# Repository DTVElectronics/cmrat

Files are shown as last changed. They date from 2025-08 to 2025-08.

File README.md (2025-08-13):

# CmRat by DTV Electronics

---

Please note: This repository is still under construction. Some files may be missing and will be uploaded soon.

---

The ‘CmRat’ carrier board allows a variety of Compute Modules (CM) to be installed and used alongside an NVMe hard drive. All the required expansion slots such as MicroSD, USB-C and a GPIO port to support a variety of Software/Linux and other FOSS solutions are also included.

Once configured the CmRat is capable of functioning as a fully-fledged micro server when paired with appropriate software. It operates consistently and robustly, ensuring reliable performance over time. Notably, it runs quietly, consumes minimal power, and boasts a compact physical form factor. These features make it an ideal choice for environments where space, energy efficiency, and reliable operation are paramount, such as home automation systems, small businesses, or edge computing setups.

Specifications:
- NVMe is designed for running the fastest/most reliable hard drives
- Ethernet and LCD Screen Support (via GPIO)
- POE, USB-C, or DC12v powered
- Large Heatsink design and quiet fan included
- Variety of 3d Printed Case designs on the market
- Designed for running Raspberry RPi CM4, CM5 or Radxa CM3/CM5

The project was originally developed by [Mirek](https://github.com/mfolejewski) under the project name ‘BitPiRat’ and has spurred a few different generations since then, with DTV Electronics finally releasing the project under the final retail version 2.8. 

Please take a look at the [included spec sheet](./spec-sheet.pdf) for more information.

## Table of Contents

- [CmRat by DTV Electronics](#cmrat-by-dtv-electronics)
  - [Table of Contents](#table-of-contents)
  - [About this repository](#about-this-repository)
  - [PCB Layout](#pcb-layout)
    - [Original Concept](#original-concept)
    - [BitPiRat Second Generation](#bitpirat-second-generation)
    - [CmRat project continues via DTV Electronics](#cmrat-project-continues-via-dtv-electronics)
    - [Final 2.8 Release Version from DTV Electronics](#final-28-release-version-from-dtv-electronics)
  - [Cases](#cases)
    - [Aluminium Retail Case](#aluminium-retail-case)
    - [3D Printed Third Party Cases](#3d-printed-third-party-cases)
  - [Add-ons](#add-ons)
    - [Examples](#examples)
  - [Supporters/Contributors](#supporterscontributors)

## About this repository

This repository contains the full manufacturing files for the CmRat, alongside spec sheets, pictures, and 3D models.

The repository is structured as follows:

- `readme-pictures/`: Contains images used in this README.
- `photos/`: Contains additional photos of the CmRat hardware.
- `manufacturing-files/`: Contains the manufacturing files for the CmRat.
  - `manufacturing-files/main-board/`: Contains Altium files for the main board of the CmRat.
  - `manufacturing-files/add-ons/`: Contains files for various add-ons.
    - `manufacturing-files/add-ons/lcd-module/`: Contains files for the LCD module add-on.
    - `manufacturing-files/add-ons/push-button/`: Contains files for the push button add-on.
- `3d-models/`: Contains 3D models of the CmRat.
- `spec-sheet.pdf`: A PDF document containing the specifications of the CmRat.
- `LICENSES/`: Contains the licenses for the manufacturing files and other content in this repository.
- `README.md`: This README file, providing an overview of the CmRat and its components.

All files in the manufacturing-files and 3d-models directory are licensed under the [CERN Open Hardware Licence Version 2 - Strongly Reciprocal](./LICENSES/CERN-OHL-S-2.0.txt).

All other files in this repository are licensed under the [Creative Commons Attribution-ShareAlike 4.0 International License](./LICENSES/CC-BY-SA-4.0.txt).

## PCB Layout

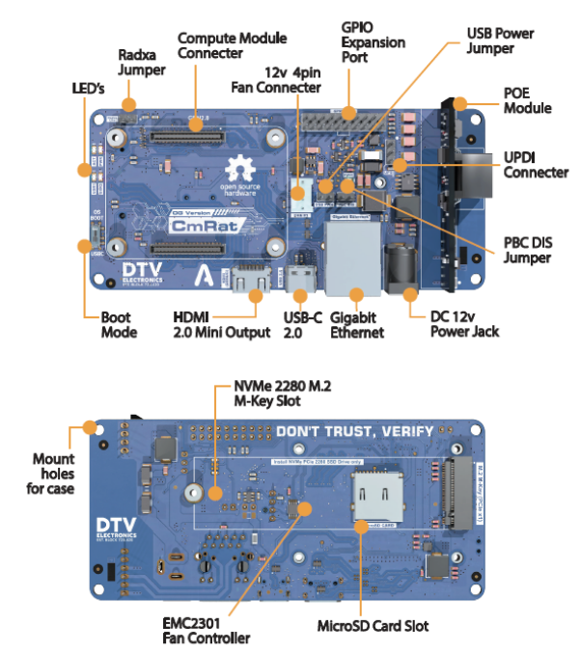
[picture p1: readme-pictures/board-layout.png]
Board Layout


### Original Concept

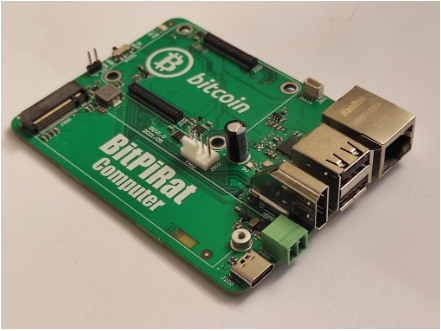
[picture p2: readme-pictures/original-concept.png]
Original Concept


### BitPiRat Second Generation

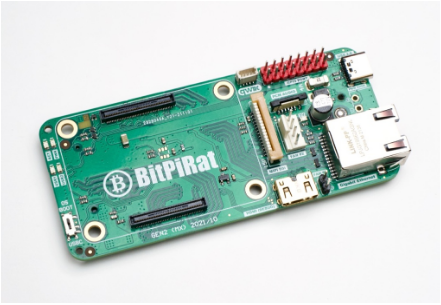
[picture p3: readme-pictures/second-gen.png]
BitPiRat Second Generation


### CmRat project continues via DTV Electronics

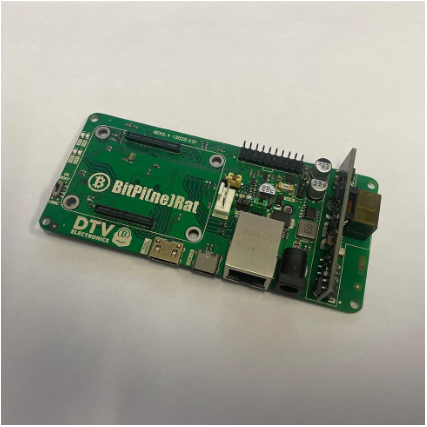
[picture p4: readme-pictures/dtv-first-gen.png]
CmRat Project Continues


### Final 2.8 Release Version from DTV Electronics

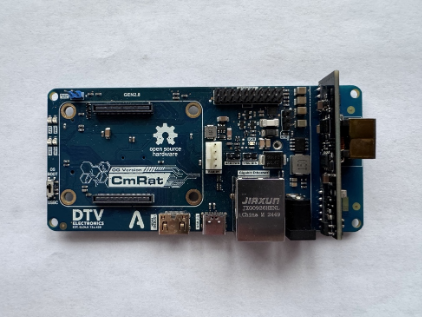
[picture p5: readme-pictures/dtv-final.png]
Final 2.8 Release Version


## Cases

### Aluminium Retail Case

The case has been designed from scratch by DTV Electronics using injection moulded production from secure and high quality ADC12 Aluminium materials. 

A fully CNC made and die casted mould allows enough airflow to keep the device running cool and quiet.

All connecter inputs are lined up perfectly within the unit allowing easy access when adding or removing cables. The PCB attaches to the bottom of the case with only 4 screws which secures everything in its entirety. The aluminium case is professionally oil painted and comes in a variety of colours. As it is essentially 2 parts (top and bottom), it allows a large amount of customisation and a variety of colours.

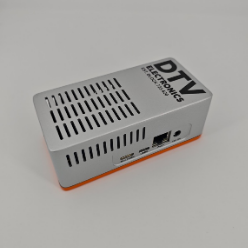
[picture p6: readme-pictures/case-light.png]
CmRat Case Light
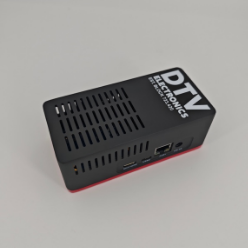
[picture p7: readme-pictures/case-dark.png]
CmRat Case Dark
 

### 3D Printed Third Party Cases

There are a variety of 3d printed inspired cases online and the files are included in this repository. 

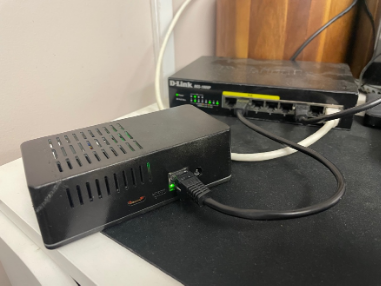
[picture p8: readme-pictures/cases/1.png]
Case 1

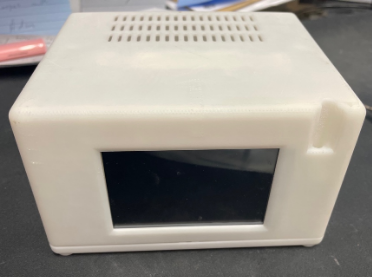
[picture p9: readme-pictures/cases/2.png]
Case 2

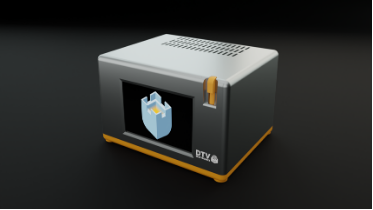
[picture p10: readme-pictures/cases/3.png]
Case 3

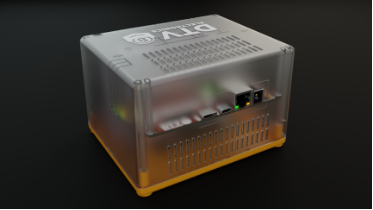
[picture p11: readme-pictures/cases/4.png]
Case 4

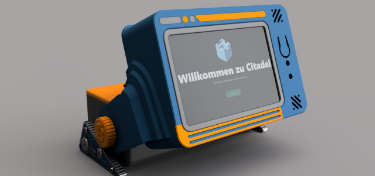
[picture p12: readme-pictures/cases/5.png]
Case 5


## Add-ons

A variety of add-ons that were originally developed by Mirek and DTV Electronics together which are included in the manufacturing files. These were not released in the retail version due to cost. The product was brought to market using only the slim case. However, there is an LCD module, Push Button Firmware, and a Push Button Controller.

This allows a screen to be attached via the GPIO port along with an on and off switch. This would have formed the concept for a larger case (shown above and listed as a 3d printed asset under ‘Max’)

All files necessary for the add-ons are included in the `manufacturing-files/addons/` directory. The firmware for the screen and push button controller is also included in the `manufacturing-files/addons/firmware/` directory. 

### Examples

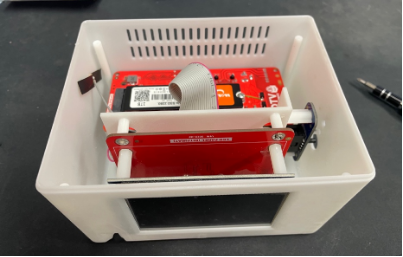
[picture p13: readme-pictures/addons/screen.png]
Screen Add-On 1

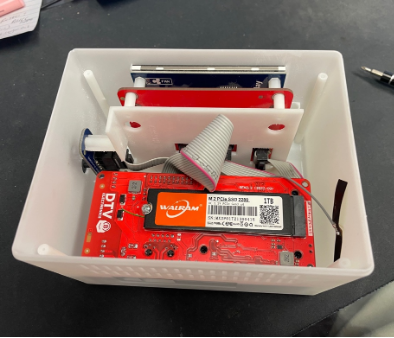
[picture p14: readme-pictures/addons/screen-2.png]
Screen Add-On 2


## Supporters/Contributors

- Adam of ‘Anlumen Technologies’
- Mirek of ‘PineBoards’
- Leo of ‘BuryRoadLabs’
- Aaron Dewes - Master Developer
- PrintergoBrr

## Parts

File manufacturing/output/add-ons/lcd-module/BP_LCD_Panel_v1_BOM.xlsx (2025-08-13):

Designator | Quantity | Component Type | Value | Package (Case) | Manufacturer | MPN | Description
C1, C2 | 2 | Capacitor | 10uF | 0603 (1608) | GENERIC | GENERIC | Capacitor; MLCC; GENERIC; TBD; TBD; TBD; TBD; SMD; 0603 (1608);
J1 | 1 | Connector | 26pin (2x13pin) | THT | GENERIC | GENERIC | Connector; 2 Row;
J2 | 1 | Connector | 20pin (2x10pin) | THT | GENERIC | GENERIC | Connector; 2 Row;
J3 | 1 | Connector | 8pin (2x4pin) | THT | GENERIC | GENERIC | Connector; 2 Row;
R1, R2, R3, R4, R5, R6, R7, R8 | 8 | Resistor | 22R | 0603 (1608) | Yageo Corporation | TBD | Resistor; Thick Film; 22R; 1%; 100mW; 100PPM; 75V; Standard; SMD; 0603 (1608);

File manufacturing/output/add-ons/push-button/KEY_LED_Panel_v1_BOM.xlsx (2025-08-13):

Designator | Quantity | Component Type | Value | Package (Case) | Manufacturer | MPN | Description
J1 | 1 | Connector | 8pin (2x4pin) | THT | GENERIC | GENERIC | Connector; 2 Row;
LED1 | 1 | LED | Green | 0805 (2012) | Foshan NationStar Optoelectronics | NCD0805G1 | Diode; LED; Green;
LED2 | 1 | LED | Red | 0805 (2012) | Foshan NationStar Optoelectronics | NCD0805R1 | Diode; LED; Red;
LP1, LP2 | 2 | Light pipe | VLP-400-F |  | BIVAR |  | LED; Light pipe
R1 | 1 | Resistor | 15k | 0603 (1608) | Yageo Corporation | TBD | Resistor; Thick Film; 15k; 1%; 100mW; 100PPM; 75V; Standard; SMD; 0603 (1608);
R2 | 1 | Resistor | 2k | 0603 (1608) | Yageo Corporation | TBD | Resistor; Thick Film; 2k2; 1%; 100mW; 100PPM; 75V; Standard; SMD; 0603 (1608);
SW1 | 1 |  | TACT Switch |  | SCHURTER | 1301.9319 | Switch; Tactile; Monostable;

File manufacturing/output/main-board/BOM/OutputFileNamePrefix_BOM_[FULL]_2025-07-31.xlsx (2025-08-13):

Designator | Quantity | Description | Value | Package (Case) | Manufacturer | MPN
C100 | 1 | Capacitor; MLCC; 100uF 6V3 | 100uF/6V3 | 1206 | Taiyo Yuden | JMK316ABJ107ML-T
C200, C908, C909, C911 | 4 | Capacitor; MLCC; 22u 16V | 22uF/16V | 0805 | Samsung Electro-Mechanics | CL21A226MOQNNNE
C303, C307, C309, C613, C702, C703, C704, C900, C912, C915, C916, C917, C918, C919, C920 | 15 | CAP SMD 10u/10V ±10% 10V X5R (0603) | 10uF | 0603 | Samsung Electro-Mechanics | CL10A106KP8NNNC
C304, C308, C310, C500, C700, C701, C800, C901 | 8 | Capacitor; MLCC; 100nF; 10V X5R | 100nF | 0603 | YAGEO | CC0603KRX7R9BB104
C400, C401, C402, C403, C404, C405, C406, C407 | 8 | RES SMD 0Ω ±1% 62.5mW ±800ppm (0402) |  |  | UNI-ROYAL(Uniroyal Elec)
C902, C906 | 2 | CAP SMD 100u/6.3V ±20% 6.3V X5R (1206) | 100u/6.3V | 1206 | Samsung Electro-Mechanics | CL31A107MQHNNNE
C903, C904 | 2 | CAP SMD 10u/50V ±10% 50V X5R (1206) | 10u/50V | 1206 | Samsung Electro-Mechanics | CL31A106KBHNNNE
C905 | 1 | CAP SMD 1u/50V ±10% 50V X5R (0603) | 1u/50V | 0603 | Samsung Electro-Mechanics | CL10A105KB8NNNC
C910, C913, C921, C922 | 4 | CAP SMD 100u/16V ±20% 16V X5R (1210) | 100uF | 1210 | Chinocera | HGC1210R5107M160NSVK
C914 | 1 | Capacitor; MLCC; 22p 50V | 22pF | 0603 | Samsung Electro-Mechanics | CL10C220JB8NNNC
D900 | 1 | Diode; Schottky; Unipolar; SMAj5.0A | SMAJ5.0A | SMA | Littelfuse | SMAJ5.0A
D901, D902 | 2 | Diode; Schottky; Unipolar; SS13 | SS13 (1A/30V) | DO-214AC (SMA) | ON Semi | SS13
D903 | 1 | Diode; Schottky; Unipolar; SK33 | SK33 (3A/SMC) | SMC | Littelfuse | SK33
D904 | 1 | DIODE SMD / SCHOTTKY / 40V 1A 600mV @ 1A (SOD-323) |  | SOD-323 | Guangdong Hottech | 1N5819WS
FUS900 | 1 | Fuse 4A | 4A/125VDC | SMD,6.1x2.5mm | Bel Fuse | 0679L4000-01
J100 | 1 | CONN THT / HEADER / PITCH 2,54mm / VERTICAL / (20 PIN) 2x10 | HDR 2x10 | THT | Ckmtw(Shenzhen Cankemeng) | B-2100S20P-B110
J103, J104 | 2 | Connector; DF40HC(3.0)-100DS-0.4V | Mezzanine, 100pin, 3.0mm | SMD | Hirose | DF40HC(3.0)-100DS-0.4V
J200 | 1 | Connector; USB 3.1 Type C; Receptacle; 24-pin; USB 2.0 Only; | U262-161N-4BVC11 | SMD | XKB Connectivity | U262-161N-4BVC11
J201, J601, J900 | 3 | CONN THT / HEADER / PITCH 2,54mm / VERTICAL / (2 PIN) | HDR 1x2 | THT | Ckmtw(Shenzhen Cankemeng) | B-2100S02P-A110
J300 | 1 | Connector; NGFF (M.2); M-Key; | M.2/NGFF M-Key H4.2 | SMD | Lotes | APCI0107-P001A
J400 | 1 | Connector; HDMI v1.4+; Type C (Mini-HDMI); | Mini HDMI connector (Type C), angled, SMD | SMD | XKB Connectivity | A71-05H4-111N1
J500 | 1 | Connector; RJ45; | LPJG0926HENL | THT | Link-PP | LPJG0926HENL
J501 | 1 | Connector; DC Barrel Jack; | 5A, 2.0mm | THT | XKB Connectivity | DC-005-5A-2.0
J600 | 1 | Connector; MicroSD Card Connector; | MicroSD Card (Slot) | SMD | TF-015 | TF-015
J802 | 1 | Connector; 1 Row; 470531000 | MLX 470531000 | THT | Molex | 470531000
J901 | 1 | CONN THT / HEADER / PITCH 2,54mm / VERTICAL / (3 PIN) | HDR 1x3 | THT | Ckmtw(Shenzhen Cankemeng) | B-2100S03P-A110
L900 | 1 | Inductor; 15u | 15uH | SMD | Changjiang Microelectronics Tech | FXL0630-150-M
L901, L903 | 2 | Inductor; 2u2 | 2u2H | SMD | Changjiang Microelectronics Tech | FXL0624-2R2-M
L902 | 1 | INDUCTOR SMD COIL / 4u7 ±20% / Power inductor Ir 2.8A Isat 3A (SMD,4.2x4.4mm) | 4u7 | SMD,4.2x4.4mm | cjiang (Changjiang Microelectronics Tech) | FXL0420-4R7-M
LED100, LED801 | 2 | Diode; LED; Red; | Red | 0805 | Foshan NationStar Optoelectronics | NCD0805R1
LED101, LED800, LED900 | 3 | Diode; LED; Green; | Green | 0805 | Foshan NationStar Optoelectronics | NCD0805G1
MECH301 | 1 | PCB; Mechanical; SMT Steel Spacer; M2.5; | M2.5, L = 2.5mm | SMD | Wurth Elektronik | 977 402 515 1
MECH800, MECH801, MECH804, MECH805 | 4 | PCB; Mechanical; SMT Steel Spacer; M2.5; | M2.5, L = 3.0mm | SMD | Wurth Elektronik | 977 403 015 1
MECH802, MECH803, MECH806, MECH807, SCR300 | 5 | Mechnical; Screw; | M2.5 |  |  | M2.5 screw
MOD100 | 1 | PCB Module; RPi Compute Module 4; | RPi CM4 Module |  | Raspberry Pi Foundation | CM4 Module
MOD900 | 1 | PCB Module; PoE Module; | DP9712 |  | SDaPo | DP9712
Q200, Q803, Q902 | 3 | Transistor; BJT; NPN; Digital; | DTC143ZE | SOT-523 | On Semiconductor | DTC143ZE
Q800, Q801, Q802 | 3 | Transistor; BJT; PNP; Digital; | DTA143ZE | SOT-523 | On Semiconductor | DTA143ZE
Q900, Q901 | 2 | Transistor; PMOS; | PMOS | SOT23 | Vishay | SI2305CDS-T1-GE3
R100, R201, R203, R205, R903, R915 | 6 | Resistor; Thick Film; 5k1; 1%; 100mW; 100PPM; 75V; Standard; SMD; 0603 (1608); | 5k1 | 0603 | UNI-ROYAL(Uniroyal Elec) | 0603WAF5101T5E
R200, R207, R713, R714 | 4 | Resistor; Thick Film; 1k; 1%; 100mW; 100PPM; 75V; Standard; SMD; 0603 (1608); | 1k | 0603 | UNI-ROYAL(Uniroyal Elec) | 0603WAF1001T5E
R202, R703, R715, R800, R804, R900, R901, R913 | 8 | Resistor; Thick Film; 15k; 1%; 100mW; 100PPM; 75V; Standard; SMD; 0603 (1608); | 15k | 0603 | UNI-ROYAL(Uniroyal Elec) | 0603WAF1502T5E
R206, R904 | 2 | Resistor; Thick Film; 100k; 1%; 100mW; 100PPM; 75V; Standard; SMD; 0603 (1608); | 100k | 0603 | UNI-ROYAL(Uniroyal Elec) | 0603WAF1003T5E
R400, R700, R701, R702, R705, R708, R709, R710, R802, R805, R920 | 11 | Resistor; Thick Film; 2k2; 1%; 100mW; 100PPM; 75V; Standard; SMD; 0603 (1608); | 2k | 0603 | UNI-ROYAL(Uniroyal Elec) | 0603WAF2001T5E
R401, R600, R803 | 3 | Resistor; Thick Film; 0R; SMD; 0603 (1608); | 0R | 0603 | UNI-ROYAL(Uniroyal Elec) | 0603WAF0000T5E
R500, R501, R704 | 3 | Resistor; Thick Film; 470R; 1%; 100mW; 100PPM; 75V; Standard; SMD; 0603 (1608); | 470R | 0603 | UNI-ROYAL(Uniroyal Elec) | 0603WAF4700T5E
R706, R707 | 2 | Resistor; Thick Film; 20k; SMD; 0603 (1608); | 20k | 0603 | UNI-ROYAL(Uniroyal Elec) | 0603WAF2002T5E
R716 | 1 | Resistor; Thick Film; 100R; 1%; 100mW; 100PPM; 75V; Standard; SMD; 0603 (1608); | 100R | 0603 | UNI-ROYAL(Uniroyal Elec) | 0603WAF1000T5E
R801 | 1 | Resistor; Thick Film; 36k; SMD; 0603 (1608); | 36k | 0603 | UNI-ROYAL(Uniroyal Elec) | 0603WAF3602T5E
R902 | 1 | Resistor; Thick Film; 5k1; 1%; 100mW; 100PPM; 75V; Standard; SMD; 0603 (1608); | 300k | 0603 | UNI-ROYAL(Uniroyal Elec) | 0603WAF3003T5E
R905 | 1 | Resistor; Thick Film; 22k; 1%; 100mW; 100PPM; 75V; Standard; SMD; 0603 (1608); | 22k | 0603 | UNI-ROYAL(Uniroyal Elec) | 0603WAF2202T5E
R914 | 1 | Resistor; Thick Film; 6k2; SMD; 0603 (1608); | 6.2k | 0603 | UNI-ROYAL(Uniroyal Elec) | 0603WAF6201T5E
SW200 | 1 | Switch; SPDT; | Slide switch | SMD | XKB Connectivity | SS-3292S-L1
U100 | 1 | IC SMD / REGULATOR - CONVERTER (INT SWI) - DC/DC - STEP-UP / 1.4A 2.7-16VIN 1MHz (SOT-23-6) |  | SOT-23-6 | Diodes Incorporated | AP3031KTR-G1
U200, U400, U401, U500, U501 | 5 | IC; TVS Arrays; ESD Protection; 4-Channel; 17kV Air; 12kV Contact; 0.3pF Capitance; TBD; SMD; TBD; | RCLAMP0524PA | DFN-10(1x2.5) | Semtech Corporation | RCLAMP0524PATCT
U201 | 1 | IC SMD / LOAD SWITCH / 2.4V - 5.5V (SOT-23-5) | SY6280AAC | SOT-23-5 | Silergy Corp | SY6280AAC
U700 | 1 | IC; MCU; tinyAVR 8-bit MCU, 20MHz, 8kB flash, 512B RAM, USART, SPI, TWI, VQFN package | ATTINY806 | VQFN20 | Microchip Technology (Atmel) | ATTINY806-MNR
U701 | 1 | ICC; LDO regulator; AP2210N-3.3, Ultra-low dropout voltage regulator, Vout = 3.3V, 300 mA, SOT23-3 package | AP2210N-3.3 | SOT23-3 | Diodes Incorporated | AP2210N-3.3TRG1
U801 | 1 | IC; Fan controller; | EMC2301 | MSOP-8 | Microchip Technology | EMC2301-1-ACZL-TR
U900 | 1 | IC; Buck regulator; AP3441 | AP3441/L | U-DFN2020-8 | Diodes Incorporated | AP3441SHE-7B
U902 | 1 | IC; Buck regulator; TD1583 | TD1583 | SOP8 | Techcode Semicon | TD1583PR

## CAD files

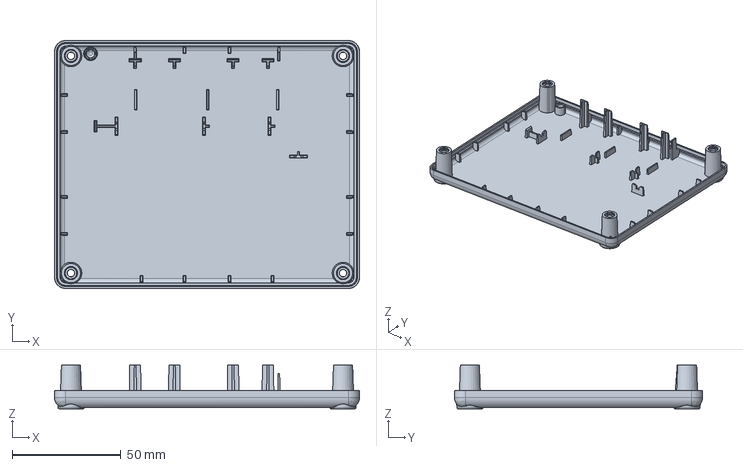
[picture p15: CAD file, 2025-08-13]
3d-models/max/02_max_bottom_cc_24.stp
140.1 x 113.9 x 20.0 mm

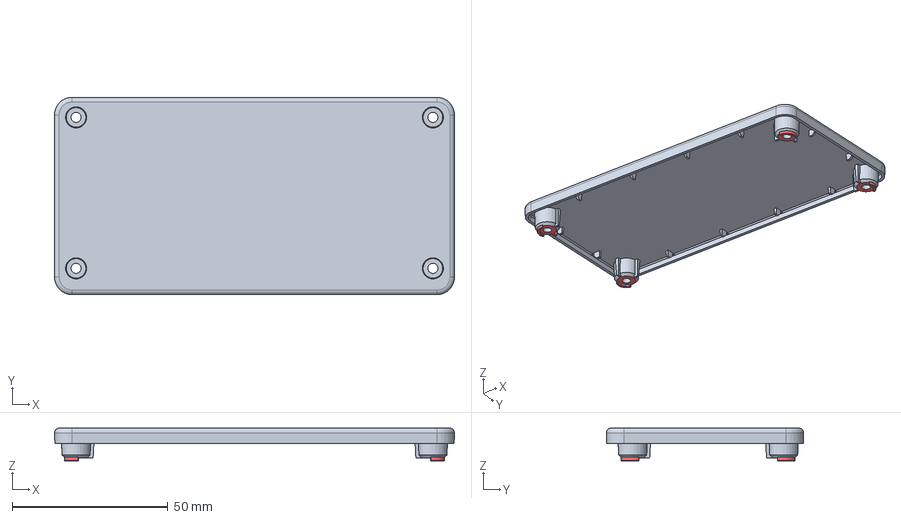
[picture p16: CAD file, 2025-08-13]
3d-models/slim/02_slim_bottom_r3_10_3_1-20231213.stp
128.2 x 63.2 x 10.5 mm

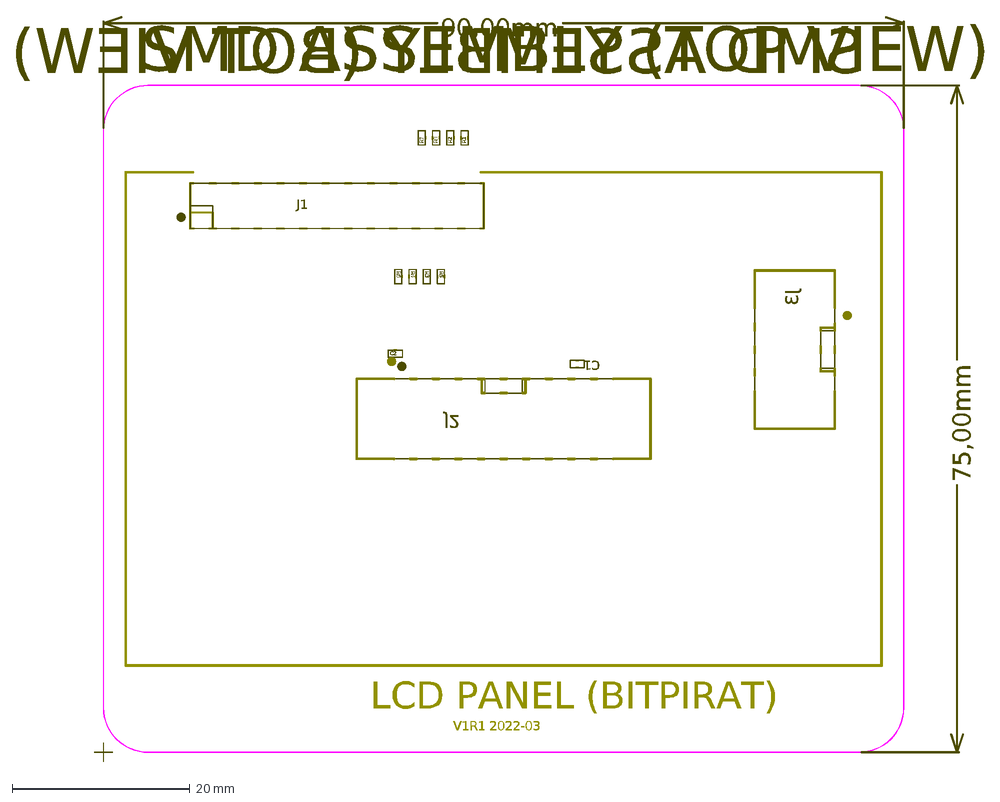
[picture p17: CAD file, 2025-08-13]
manufacturing/output/add-ons/lcd-module/BP_LCD_Panel_v1.DXF
SMD ASSEMBLY (BOT VIEW)
SMD ASSEMBLY (TOP VIEW)
LCD PANEL (BITPIRAT)
V1R1 2022-03
90,00mm
75,00mm
J3
C2
R8
R7
R6
R5
R4
R3
R2
R1
J2
J1
C1

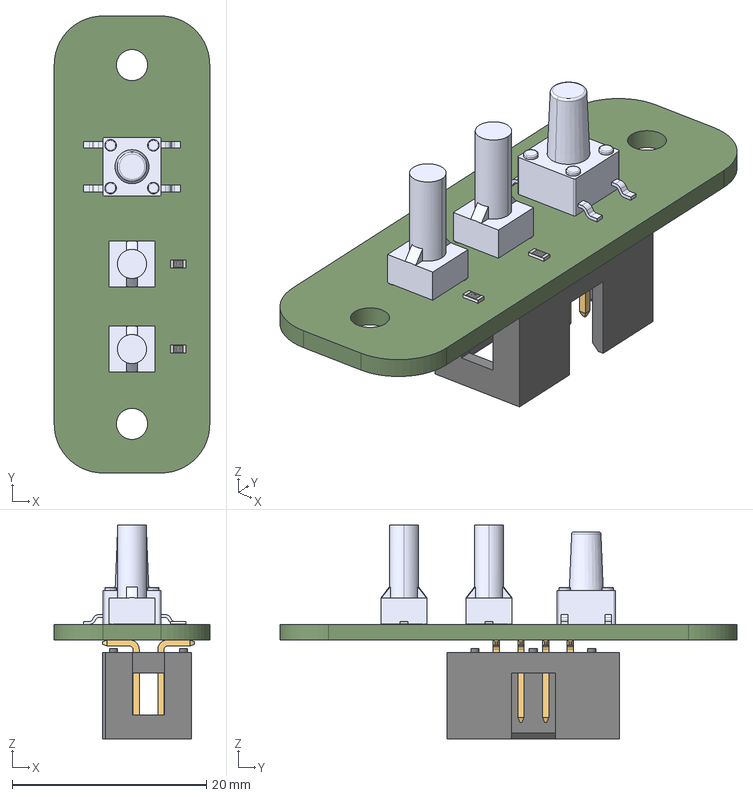
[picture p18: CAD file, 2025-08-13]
manufacturing/output/add-ons/push-button/KEY_LED_Panel_v1.step
16.0 x 47.0 x 22.0 mm
BIVAR_VLP-400-F x 2
User_Library-led_0805
User_Library-led_0805G
6120xx20621_PIN x 8
RESC1608X_0603 x 2

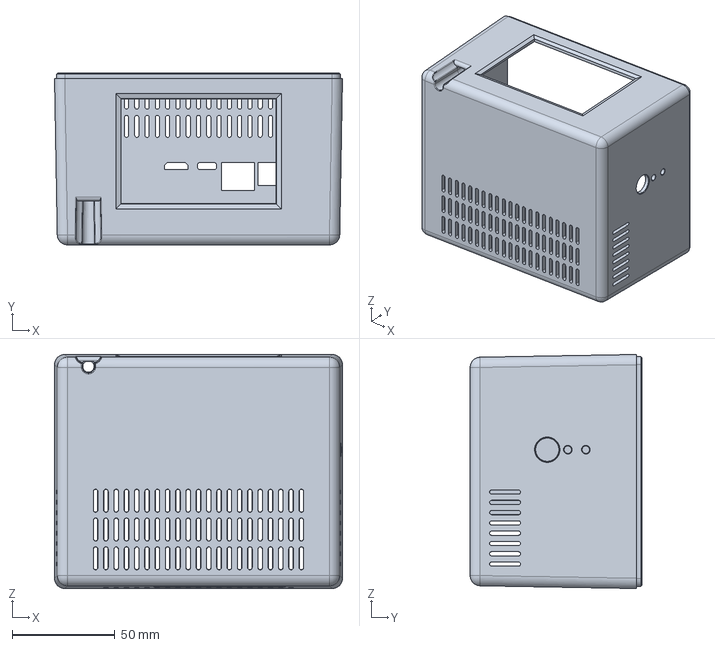
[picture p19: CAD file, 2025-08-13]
3d-models/max/01_max_top_bb_28.stp
140.0 x 83.5 x 113.8 mm

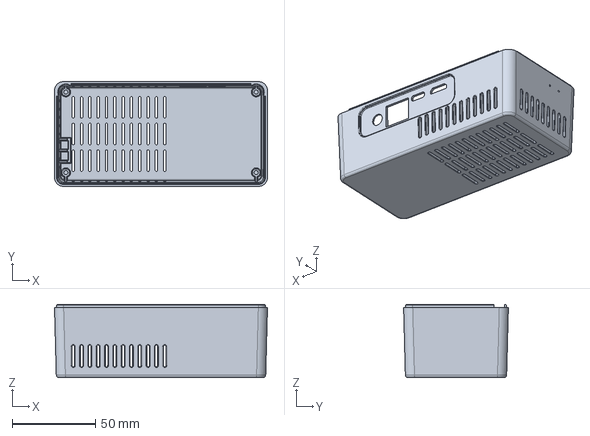
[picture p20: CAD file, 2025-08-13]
3d-models/slim/01_slim_top_r2_9_2_1.stp
128.0 x 63.0 x 44.0 mm

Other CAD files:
manufacturing/output/add-ons/push-button/KEY_LED_Panel_v1.DXF

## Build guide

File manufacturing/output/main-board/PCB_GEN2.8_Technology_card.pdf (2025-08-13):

## [1] Basic specification

LAYERS
4

LAMINATE TYPE
FR4

BOARD THICKNESS[1]
1.60[mm] ± 10%

EXTERNAL COPPER THICKNESS[2]
35 [um]

### see PCB stackup on detailed drawing section

SURFACE TREATMENT

### ENIG

NON PLATED TH

### YES

VIAS
TH

CTI

### NOT SPECIFIED

- Board thickness refers to the final PCB, unless otherwise specified in the further parts of the document.
- External copper thickness refers to the final copper, unless otherwise specified in the further parts of the document.

## [2] Special layers

## [3] Additional requirements

FULL PANELS ONLY NO | ELECTRICAL TEST REQUIRED YES
UL CETRIFICATE REQUIRED YES | ROHS COMPLIANT YES

CONTROLLED IMPEDANCE TRACKS

### YES

SOLDERMASK TYPE

### MATT

SOLDERMASK TOP

### BLUE

SOLDERMASK BOTTOM

### BLUE

GRAPHITE COATING
NO

SILKSCREEN TOP

### WHITE

SILKSCREEN BOTTOM

### WHITE

MANUFACTURER’s LOGO & DATE CODE

### YES

### silkscreen bottom

UL LOGO

### YES

### silkscreen bottom

## [4] Layer set and documentation

Name | File name | Comment
LAYER L1 (TOP) | *.GTL | Gerber RS274X (4.4 metric, no suppression)
LAYER L2 (internal) | *.G1 | Gerber RS274X (4.4 metric, no suppression)
LAYER L3 (internal) | *.G2 | Gerber RS274X (4.4 metric, no suppression)
LAYER L4 (BOTTOM) | *.GBL | Gerber RS274X (4.4 metric, no suppression)
SOLDERMASK TOP | *.GTS | Gerber RS274X (4.4 metric, no suppression)
SOLDERMASK BOTTOM | *.GBS | Gerber RS274X (4.4 metric, no suppression)
SILKSCREEN TOP | *.GTO | Gerber RS274X (4.4 metric, no suppression)
SILKSCREEN BOTTOM | *.GBO | Gerber RS274X (4.4 metric, no suppression)
BOARD OUTLINE | *.GM1 | Gerber RS274X (4.4 metric, no suppression)
DRILL PLATED | *-RoundHoles-Plated.TXT | NC Drill, Excellon (4.4 metric, abs., no suppression)
DRILL NON PLATED | *-RoundHoles-NonPlated.TXT | NC Drill, Excellon (4.4 metric, abs., no suppression)
SLOT PLATED | *-SlotHoles-Plated.TXT | NC Drill, Excellon (4.4 metric, abs., no suppression)

## [5] Remarks

1. See chapter 6 for the required PCB board stackup.
2. Manufactured board shall align to IPC-2615 (Printed Board Dimensions and Tolerances) unless otherwise specified in other parts of the document.
3. PCB board has impedance control of the differential pairs and should be manufactured as 90 and 100 Ohm with tolerance ±10% – see the detailed requirements described in chapter [7].
4. PCB Marking - proposed field position for Manufacturer Logo, Date Code and UL-marking for single PCB board and PCB panel was described in chapter [9].

## [6] Required board stackup

### Stackup name = JLC2313

Total board thickness = 1.60mm ±10%.
Core => FR4, thickness = 1.265 mm. Prepreg => 1x 2313, thickness = 0.1 mm.

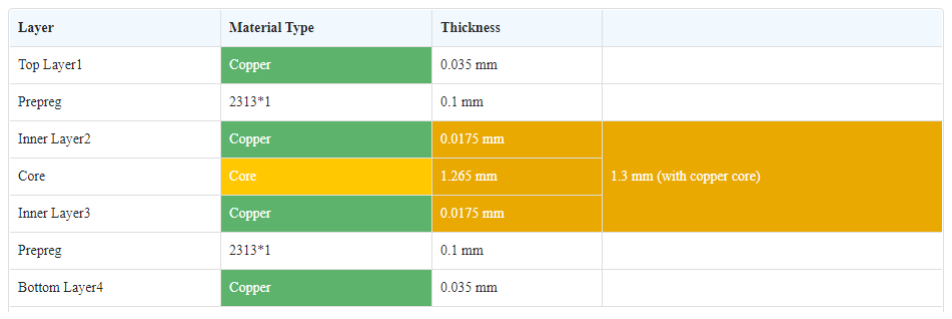
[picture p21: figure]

### Fig. 1. Required PCB board stackup

## [7] Marking

Proposed field position for Manufacturer Logo, Date Code and UL-marking.

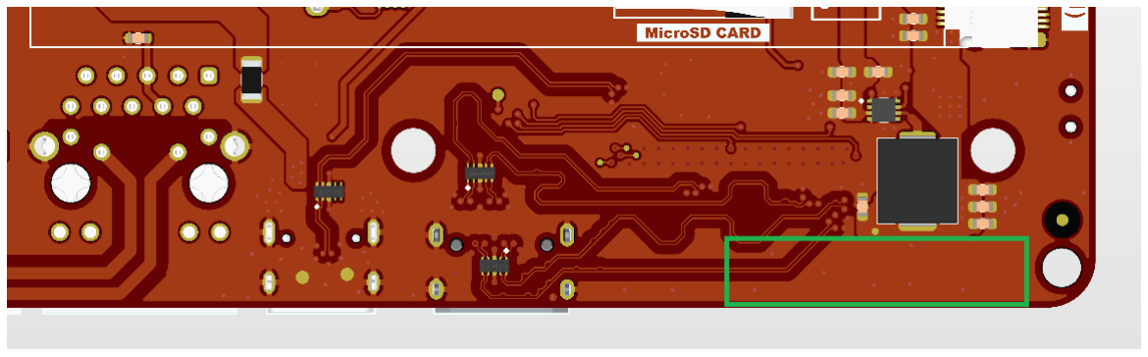
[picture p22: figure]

Dra. 5. – Proposed field position for Manufacturer Logo, Date Code and UL-marking. GREEN marked,

### SILKSCREEN BOTTOM LAYER (detail of the bottom side of the PCB)

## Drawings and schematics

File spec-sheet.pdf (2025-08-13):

### CmRat Introduction

# REFERENCE

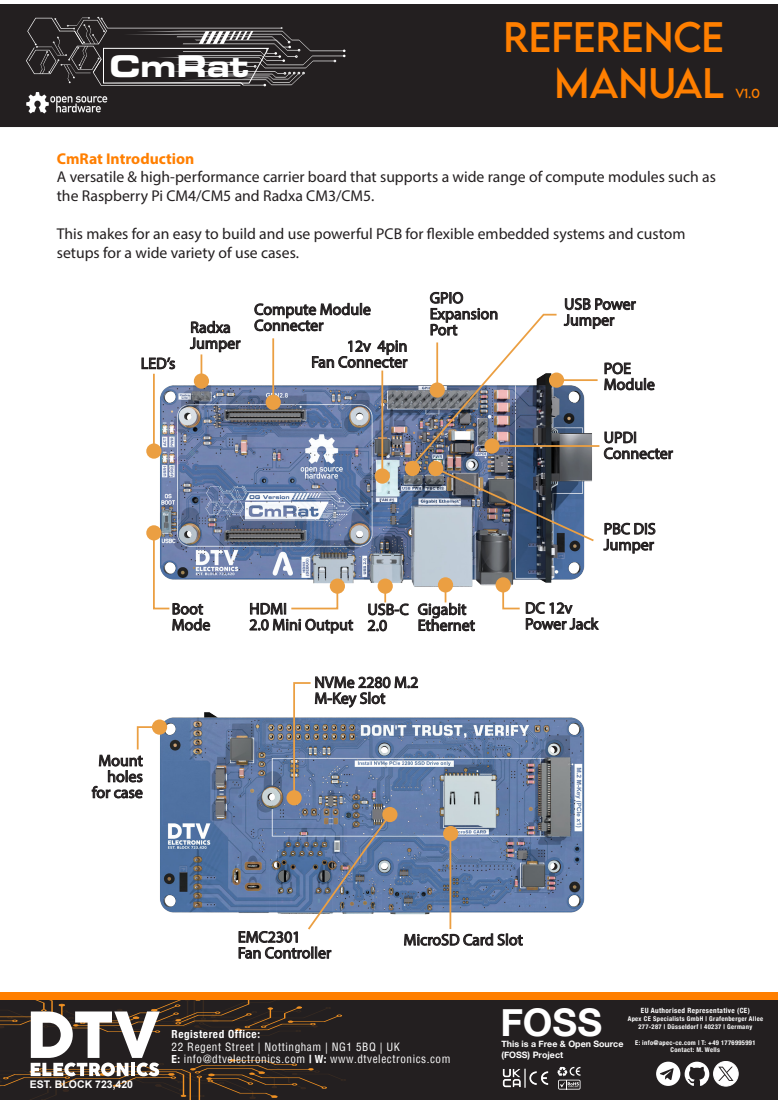
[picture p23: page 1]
POE Module; 12v 4pin Fan Connecter; GPIO Expansion Port; Gigabit Ethernet; Mount holes for case; Compute Module Connecter; HDMI 2.0 Mini Output; USB-C 2.0; Radxa Jumper; Boot Mode; LED’s; NVMe 2280 M.2 M-Key Slot; EMC2301 Fan Controller; USB Power Jumper; PBC DIS Jumper; UPDI Connecter; DC 12v Power Jack; MANUAL V1.0; Contact: M. Wells; EST. BLOCK 723,420; CmRat

A versatile & high-performance carrier board that supports a wide range of compute modules such as
the Raspberry Pi CM4/CM5 and Radxa CM3/CM5.

This makes for an easy to build and use powerful PCB for flexible embedded systems and custom
setups for a wide variety of use cases.

MicroSD Card Slot
FOSS

EU Authorised Representative (CE)
Apex CE Specialists GmbH | Grafenberger Allee
277-287 | Düsseldorf | 40237 | Germany
E: info@apec-ce.com | T: +49 1776995991

Registered Office:
22 Regent Street | Nottingham | NG1 5BQ | UK
E: info@dtvelectronics.com | W: www.dtvelectronics.com

This is a Free & Open Source
(FOSS) Project

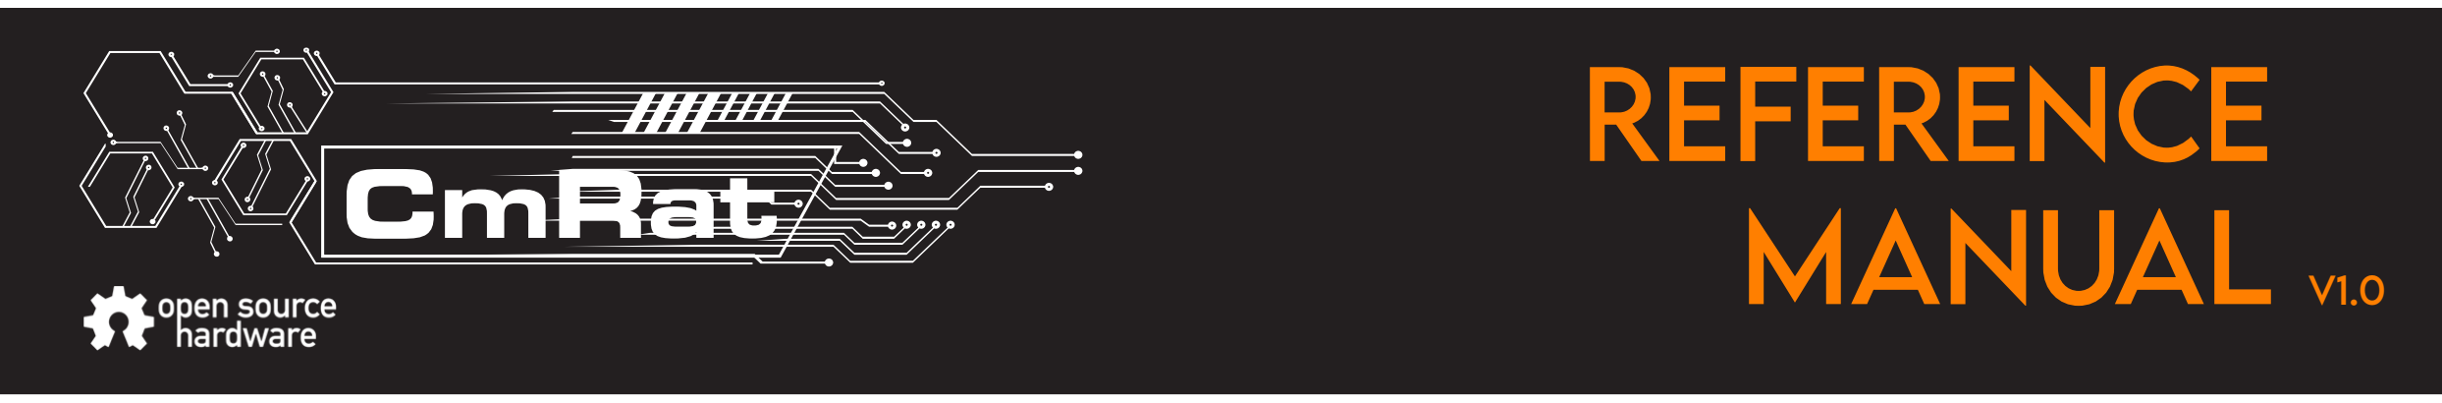
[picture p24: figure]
MANUAL V1.0

### LED’s

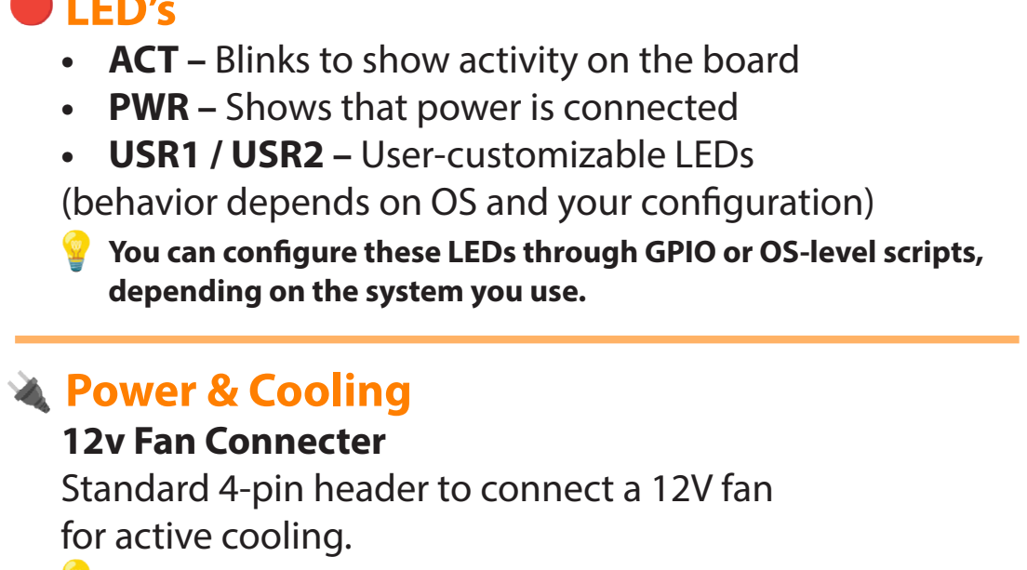
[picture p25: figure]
• PWR – Shows that power is connected • USR1 / USR2 – User-customizable LEDs; depending on the system you use. Power & Cooling 12v Fan Connecter; for active cooling.

- ACT – Blinks to show activity on the board

(behavior depends on OS and your configuration)
You can configure these LEDs through GPIO or OS-level scripts,

Standard 4-pin header to connect a 12V fan

Useful when overclocking or running heavy workloads
on CM’s.

DC Power Jack (12V)
Use a standard 12V DC adapter with a 2.1mm barrel plug. Recommended: 12V @ 1A (same as PoE power spec).
Avoid higher voltages or currents – it may damage your board!
PoE Module
Optional module for Power over Ethernet (PoE)
Complies with IEEE802.3af (Class 0: 0.44W to 12.95W).
Saves you from using a separate power cable – power and Ethernet in one!

### Compute & Booting

Compute Module connecter
Two 100-pin mezzanine connecters for installing a Raspberry Pi CM5 module.

Boot Mode Switch
Choose the boot source:
- ‘OS Boot’ – boots from storage on the Compute Module (eMMC, MicroSD, NVMe)
- ‘USB-C’ – connect to a PC and flash the OS or access the CM5 directly

### Storage Options

MicroSD Card Slot
Alternative OS install method or extra storage.
Great for testing builds before committing to eMMC/NVMe.
NVMe M.2 Slot (2280 M-Key)
Full-size NVMe SSD support.
Tested with 2TB, should also work with larger (4/8TB) drives.
Make sure your OS supports NVMe boot if you’re not using eMMC.

### Connectivity

Gigabit Ethernet
Standard RJ45 port for wired internet.
Combine with PoE to simplify wiring in enclosures.
USB-C 2.0 Port
For USB devices (e.g. keyboards, storage) or power (see jumper config).

HDMI 2.0 Output
Connect a monitor or TV – if supported by your OS.
Great for debugging or graphical applications.

### Expansion & Add-ons

GPIO Expansion Header
20 pins exposed for connecting sensors, buttons, relays, etc.
Can also act as a serial/debug console depending on OS config.

UPDI connecter
For programming the onboard ATtiny806 microcontroller (Microchip) using UPDI protocol.
Needed only if you’re modifying the board-level firmware or using the ATtiny for automation. The board itself can also work independently if CM is meant to just run out of the box.
EMC2301 Fan Controller
The I²C fan speed controller and monitor.
Supports PWM fans and temperature-based speed profiles.

### Jumpers (Optional Settings)

USB PWR Jumper
Allows powering the board from a 5V USB-C power adapter.
Perfect for development benches – no need for DC jack or PoE.
PBC DIS Jumper
When enabled (default), the board powers on automatically once any power source is connected.
Remove this jumper if you want to control power manually via a switch or onboard microcontroller.
Radxa Jumper
Enable only if you’re using Radxa CM3 modules that boot from MicroSD.
Not needed for Raspberry Pi Compute Modules.

### Mounting

Mounting Holes
Standard mounting points for installing the board into an enclosure or custom case.

E

J

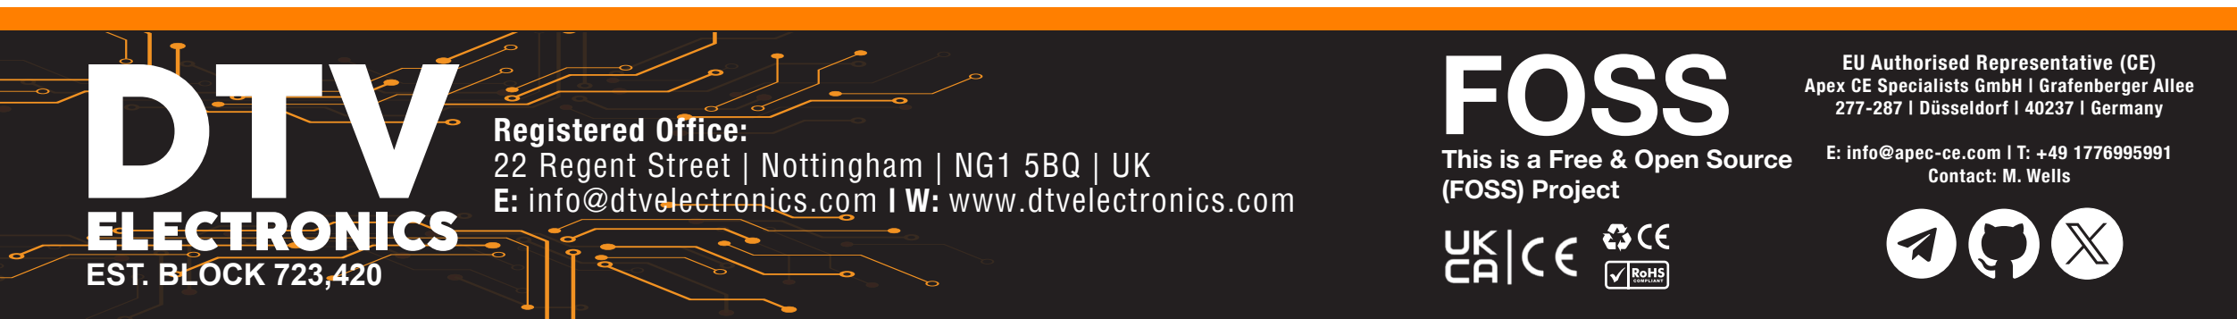
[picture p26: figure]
FOSS

### Schematics / Technology/Assembly Cards
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

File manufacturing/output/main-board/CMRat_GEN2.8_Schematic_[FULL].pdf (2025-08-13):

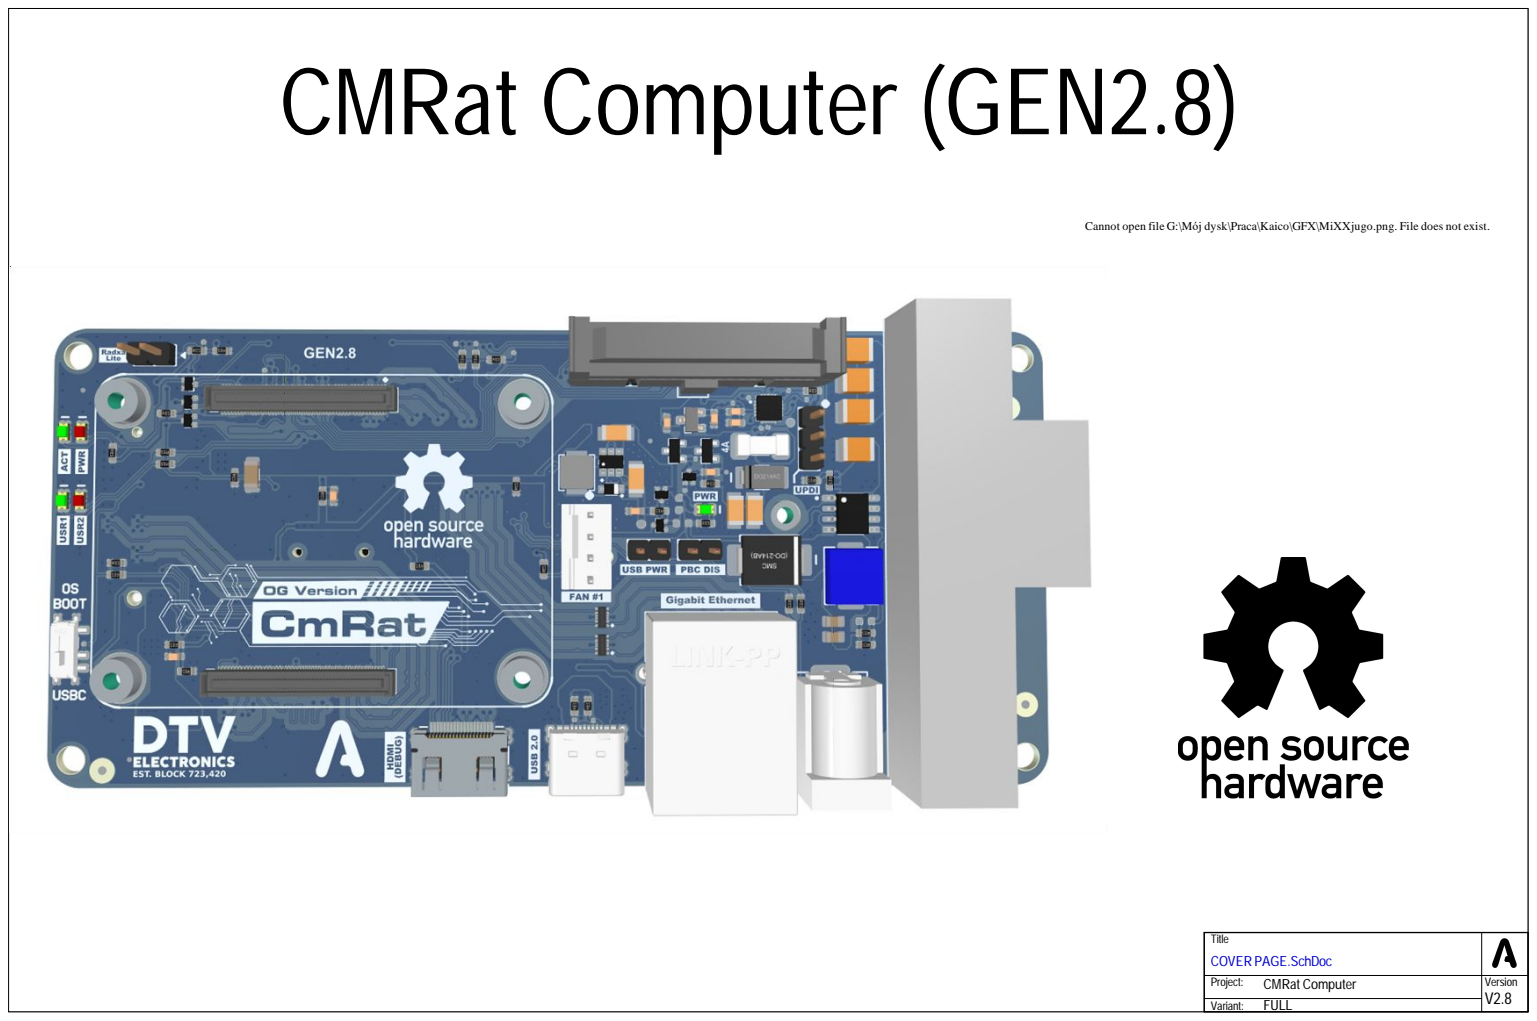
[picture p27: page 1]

Cannot open file G:\Mój dysk\Praca\Kaico\GFX\MiXXjugo.png. File does not exist.

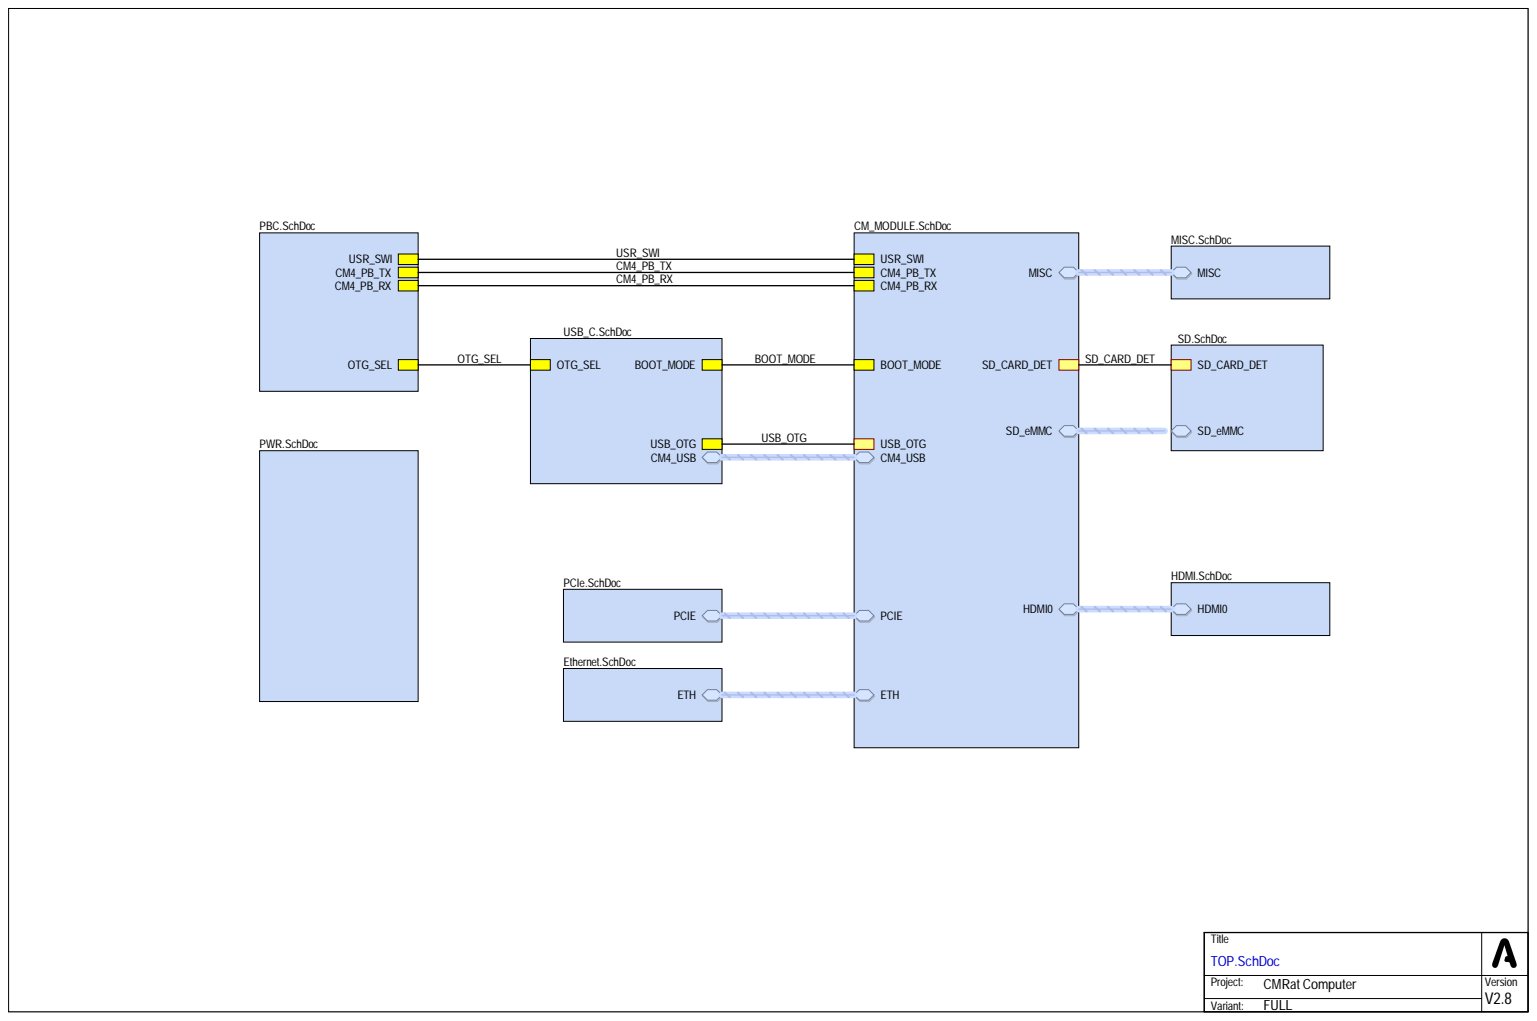
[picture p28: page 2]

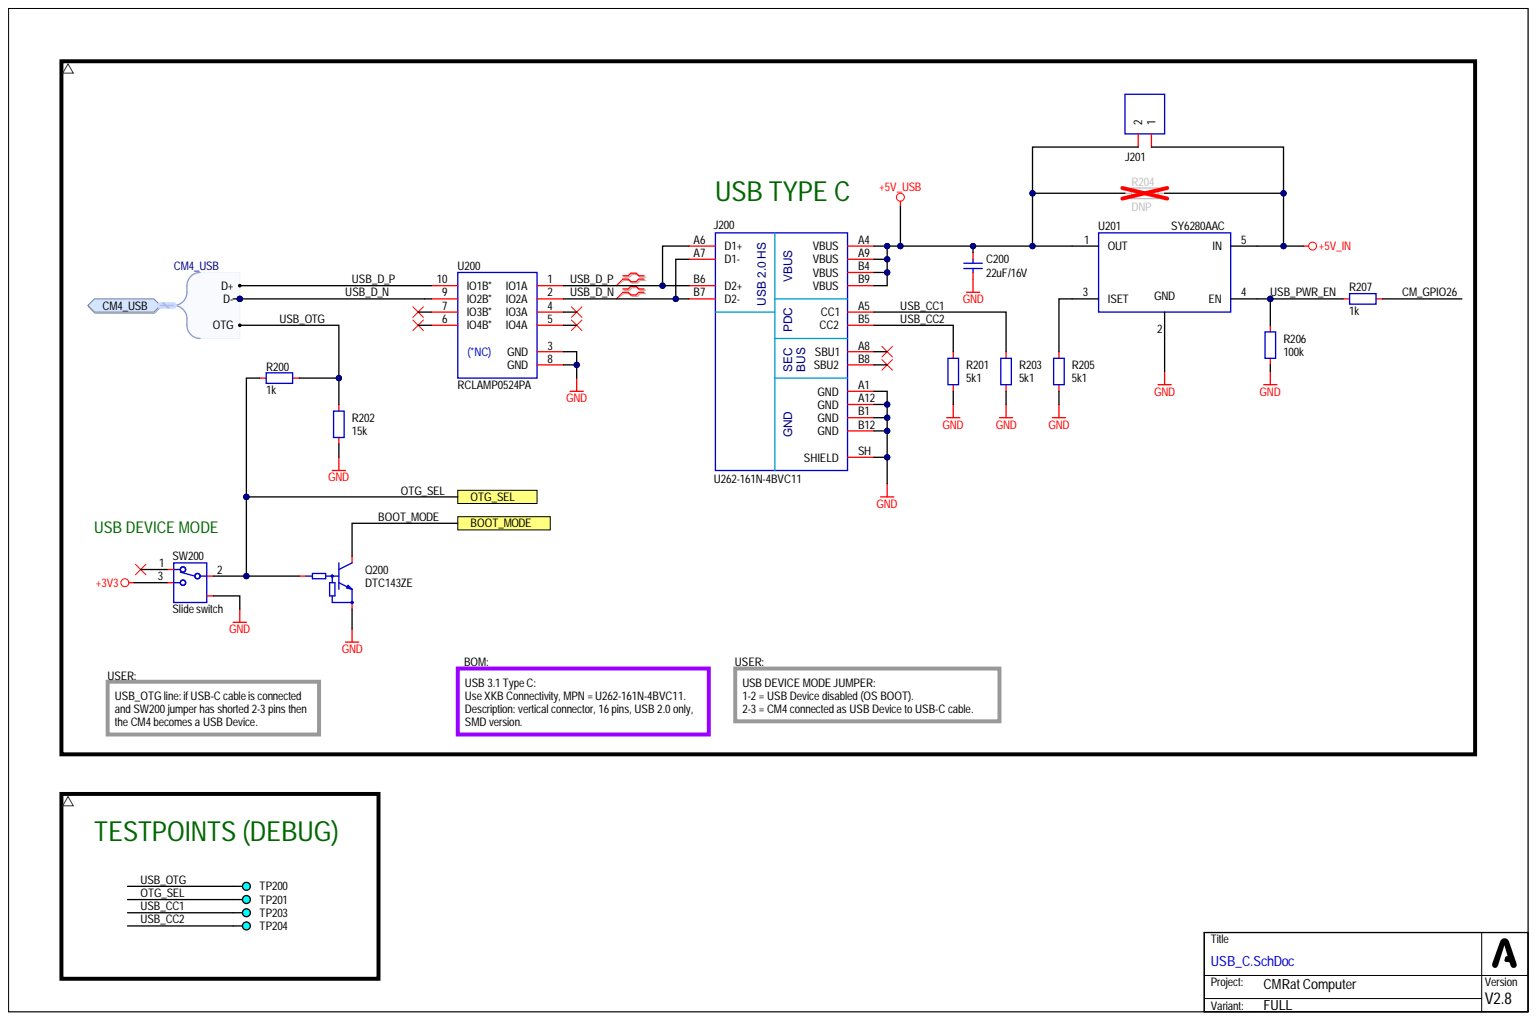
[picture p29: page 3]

GND VBUS PDC SEC

BOM:
USB 3.1 Type C:
Use XKB Connectivity, MPN = U262-161N-4BVC11.
Description: vertical connector, 16 pins, USB 2.0 only,
SMD version.

USER:
USB DEVICE MODE JUMPER:
1-2 = USB Device disabled (OS BOOT).
2-3 = CM4 connected as USB Device to USB-C cable.

USB_OTG line: if USB-C cable is connected
and SW200 jumper has shorted 2-3 pins then
the CM4 becomes a USB Device.

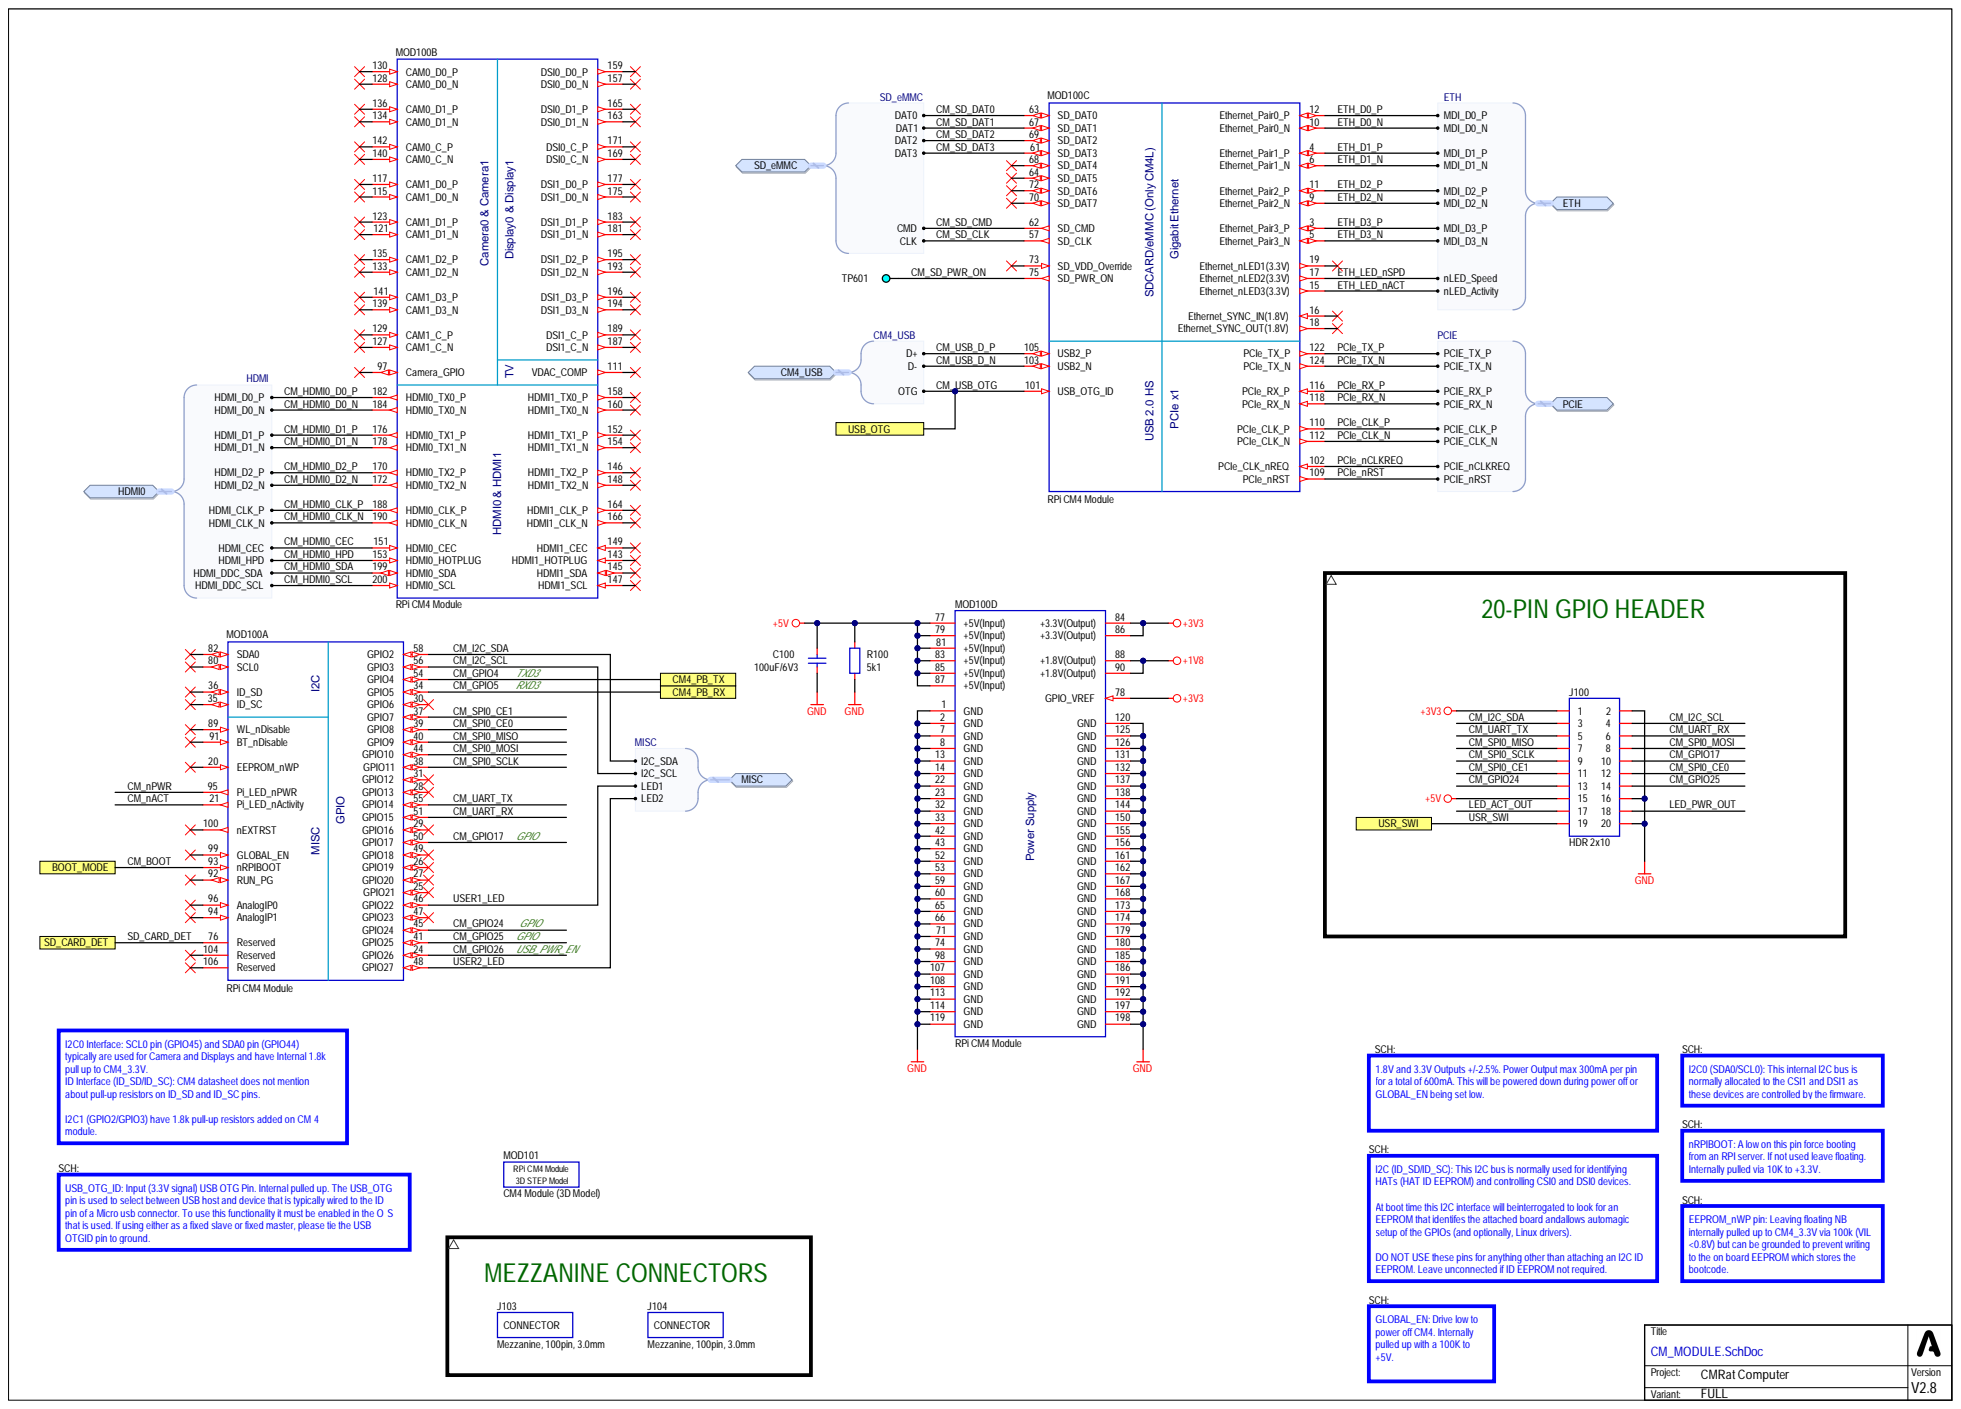
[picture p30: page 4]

SDCARD/eMMC (Only CM4L) USB 2.0 HS

SCH: I2C0 Interface: SCL0 pin (GPIO45) and SDA0 pin (GPIO44)
typically are used for Camera and Displays and have Internal 1.8k
pull up to CM4_3.3V.
ID Interface (ID_SD/ID_SC): CM4 datasheet does not mention
about pull-up resistors on ID_SD and ID_SC pins.

SCH:
1.8V and 3.3V Outputs +/-2.5%. Power Output max 300mA per pin
for a total of 600mA. This will be powered down during power off or
GLOBAL_EN being set low.

I2C0 (SDA0/SCL0): This internal I2C bus is
normally allocated to the CSI1 and DSI1 as
these devices are controlled by the firmware.

I2C1 (GPIO2/GPIO3) have 1.8k pull-up resistors added on CM4
module.

nRPIBOOT: A low on this pin force booting
from an RPI server. If not used leave floating.
Internally pulled via 10K to +3.3V.

I2C (ID_SD/ID_SC): This I2C bus is normally used for identifying
HATs (HAT ID EEPROM) and controlling CSI0 and DSI0 devices.

USB_OTG_ID: Input (3.3V signal) USB OTG Pin. Internal pulled up. The USB_OTG
pin is used to select between USB host and device that is typically wired to the ID
pin of a Micro usb connector. To use this functionality it must be enabled in the OS
that is used. If using either as a fixed slave or fixed master, please tie the USB
OTGID pin to ground.

At boot time this I2C interface will beinterrogated to look for an
EEPROM that identifes the attached board andallows automagic
setup of the GPIOs (and optionally, Linux drivers).

EEPROM_nWP pin: Leaving floating NB
internally pulled up to CM4_3.3V via 100k (VIL
<0.8V) but can be grounded to prevent writing
to the on board EEPROM which stores the
bootcode.

DO NOT USE these pins for anything other than attaching an I2C ID
EEPROM. Leave unconnected if ID EEPROM not required.

GLOBAL_EN: Drive low to
power off CM4. Internally
pulled up with a 100K to

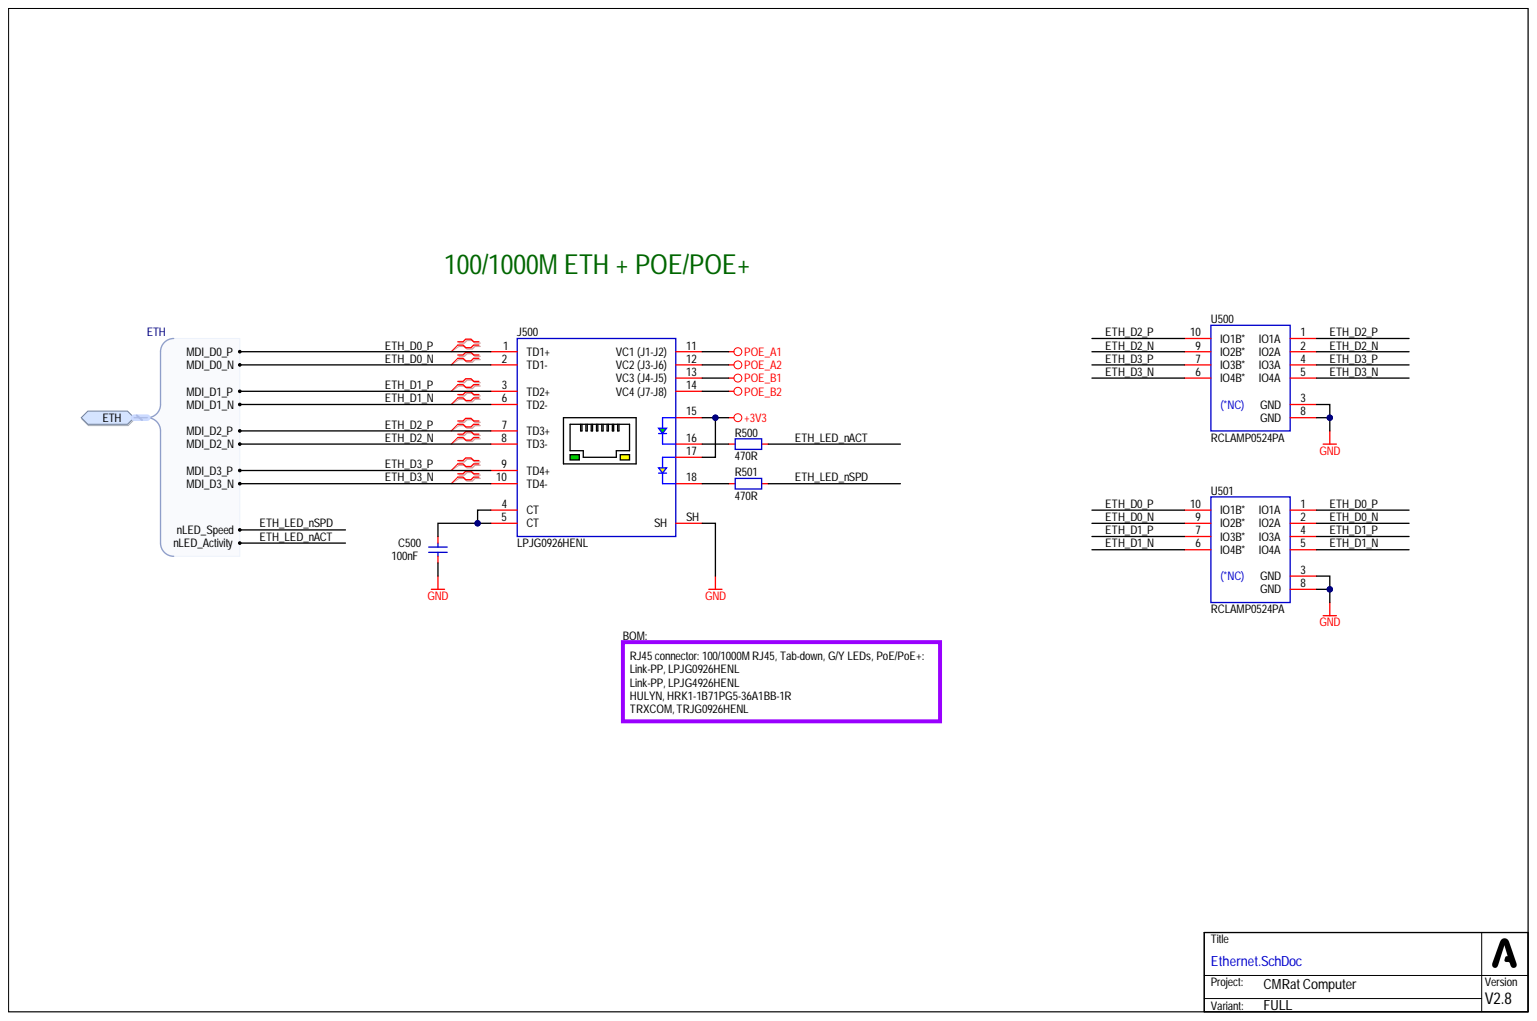
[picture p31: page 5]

BOM:
RJ45 connector: 100/1000M RJ45, Tab-down, G/Y LEDs, PoE/PoE+:
Link-PP, LPJG0926HENL
Link-PP, LPJG4926HENL
HULYN, HRK1-1B71PG5-36A1BB-1R
TRXCOM, TRJG0926HENL

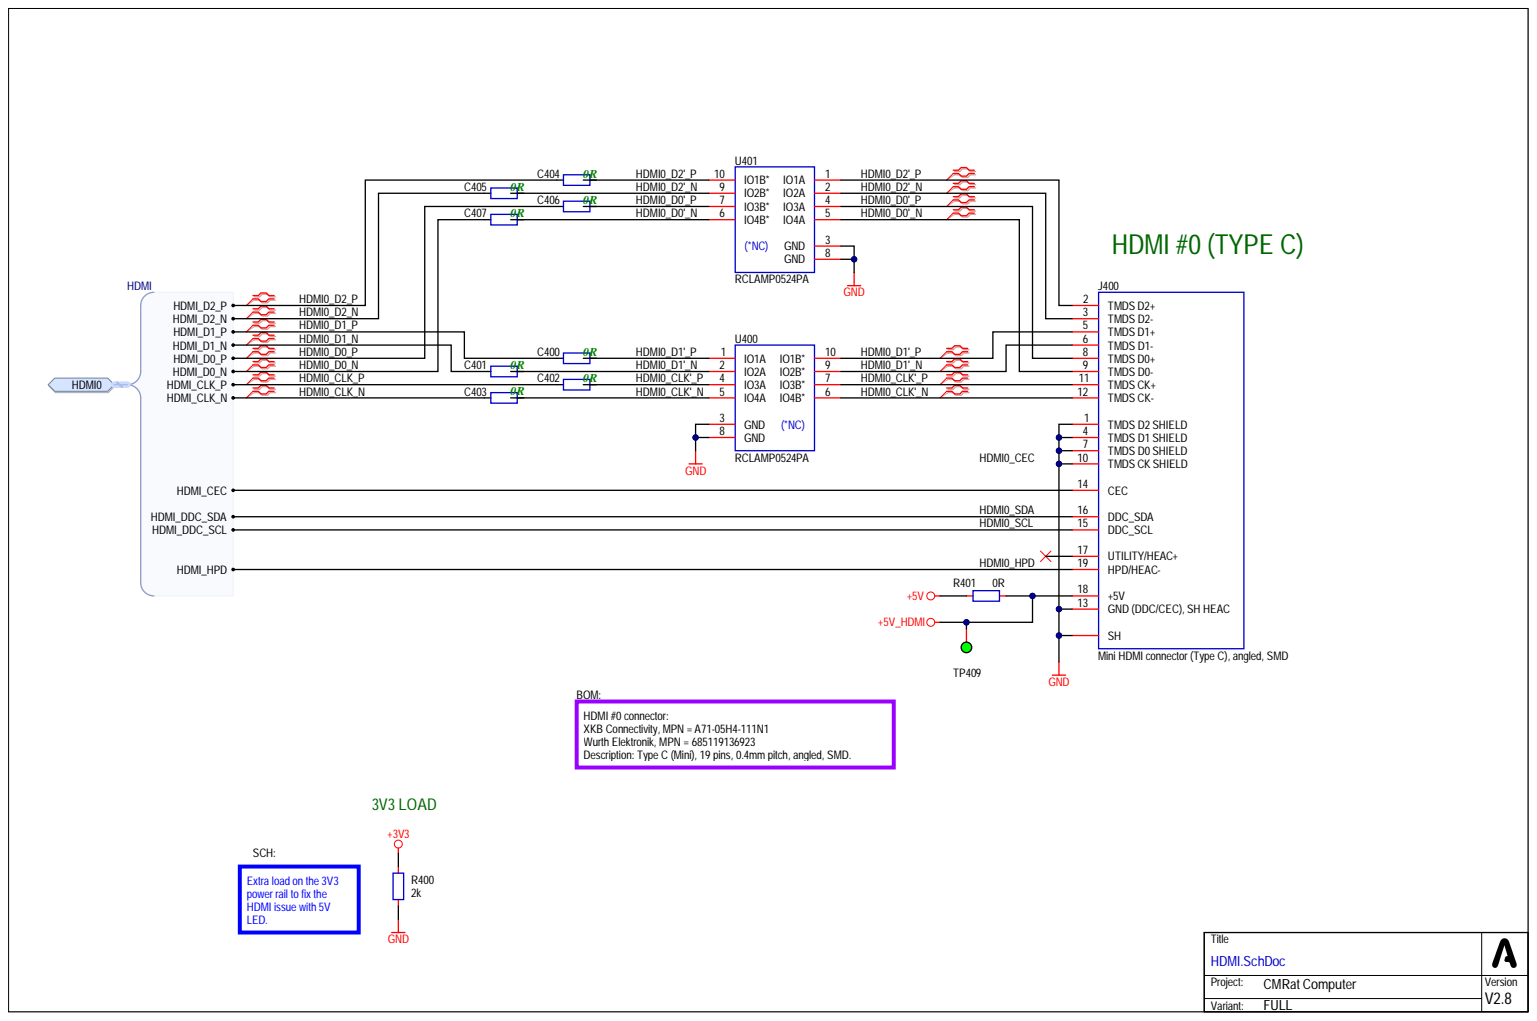
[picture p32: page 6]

Mini HDMI connector (Type C), angled, SMD

BOM:
HDMI #0 connector:
XKB Connectivity, MPN = A71-05H4-111N1
Wurth Elektronik, MPN = 685119136923
Description: Type C (Mini), 19 pins, 0.4mm pitch, angled, SMD.

Extra load on the 3V3
power rail to fix the
HDMI issue with 5V
LED.

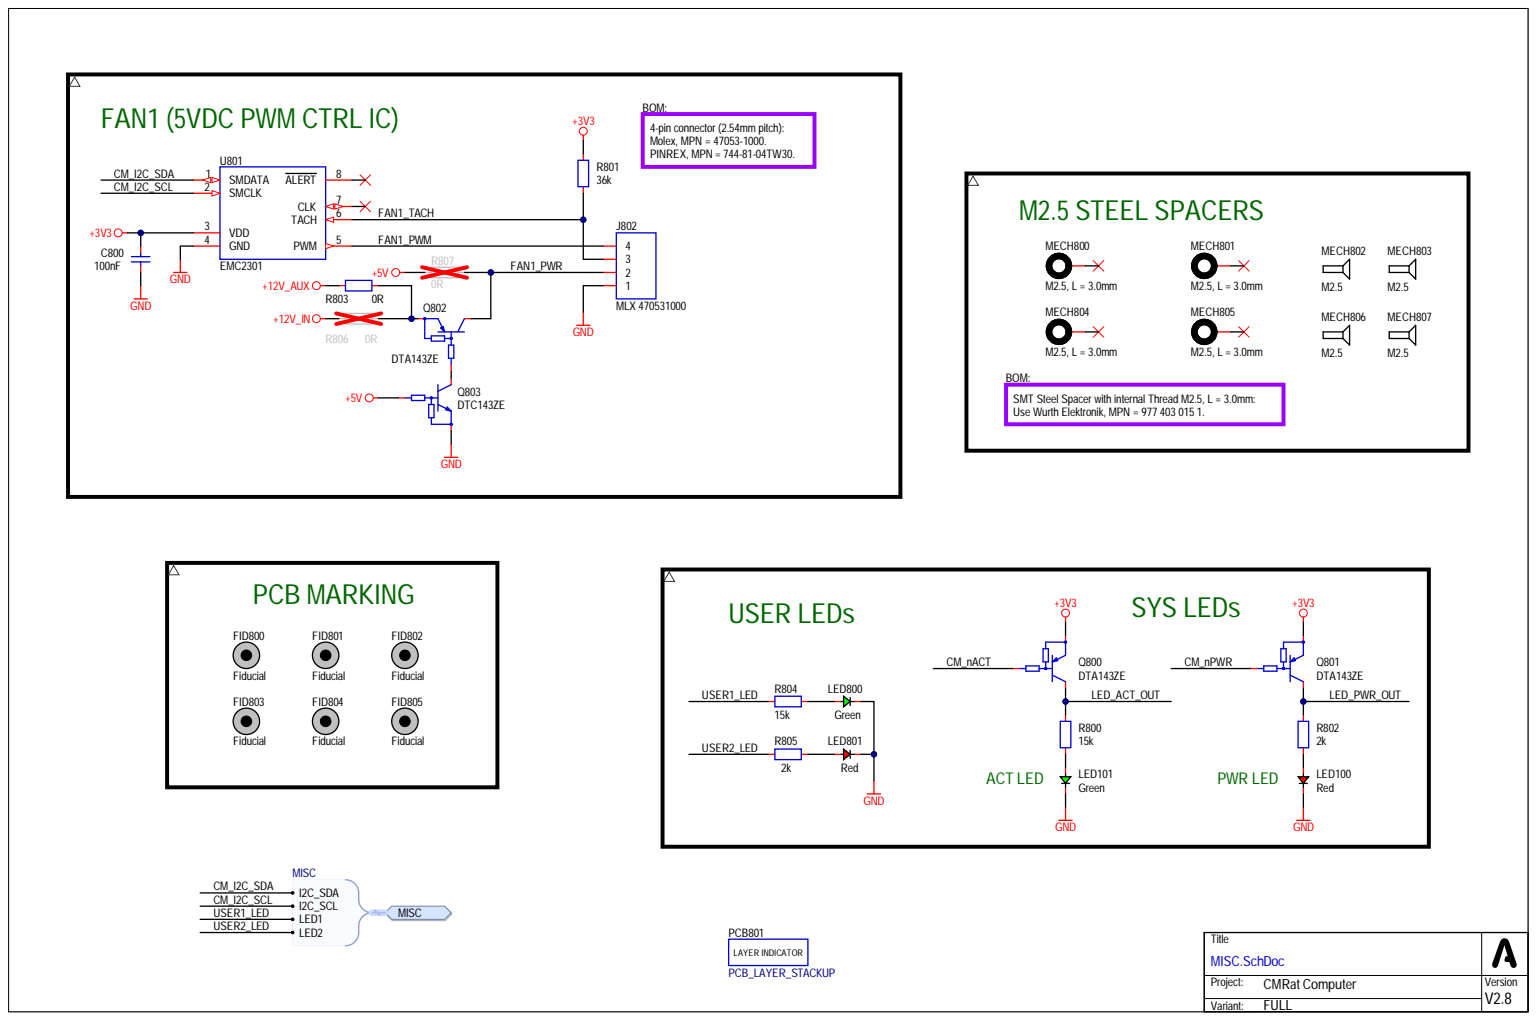
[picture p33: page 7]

BOM:
SMT Steel Spacer with internal Thread M2.5, L = 3.0mm:
Use Wurth Elektronik, MPN = 977 403 015 1.

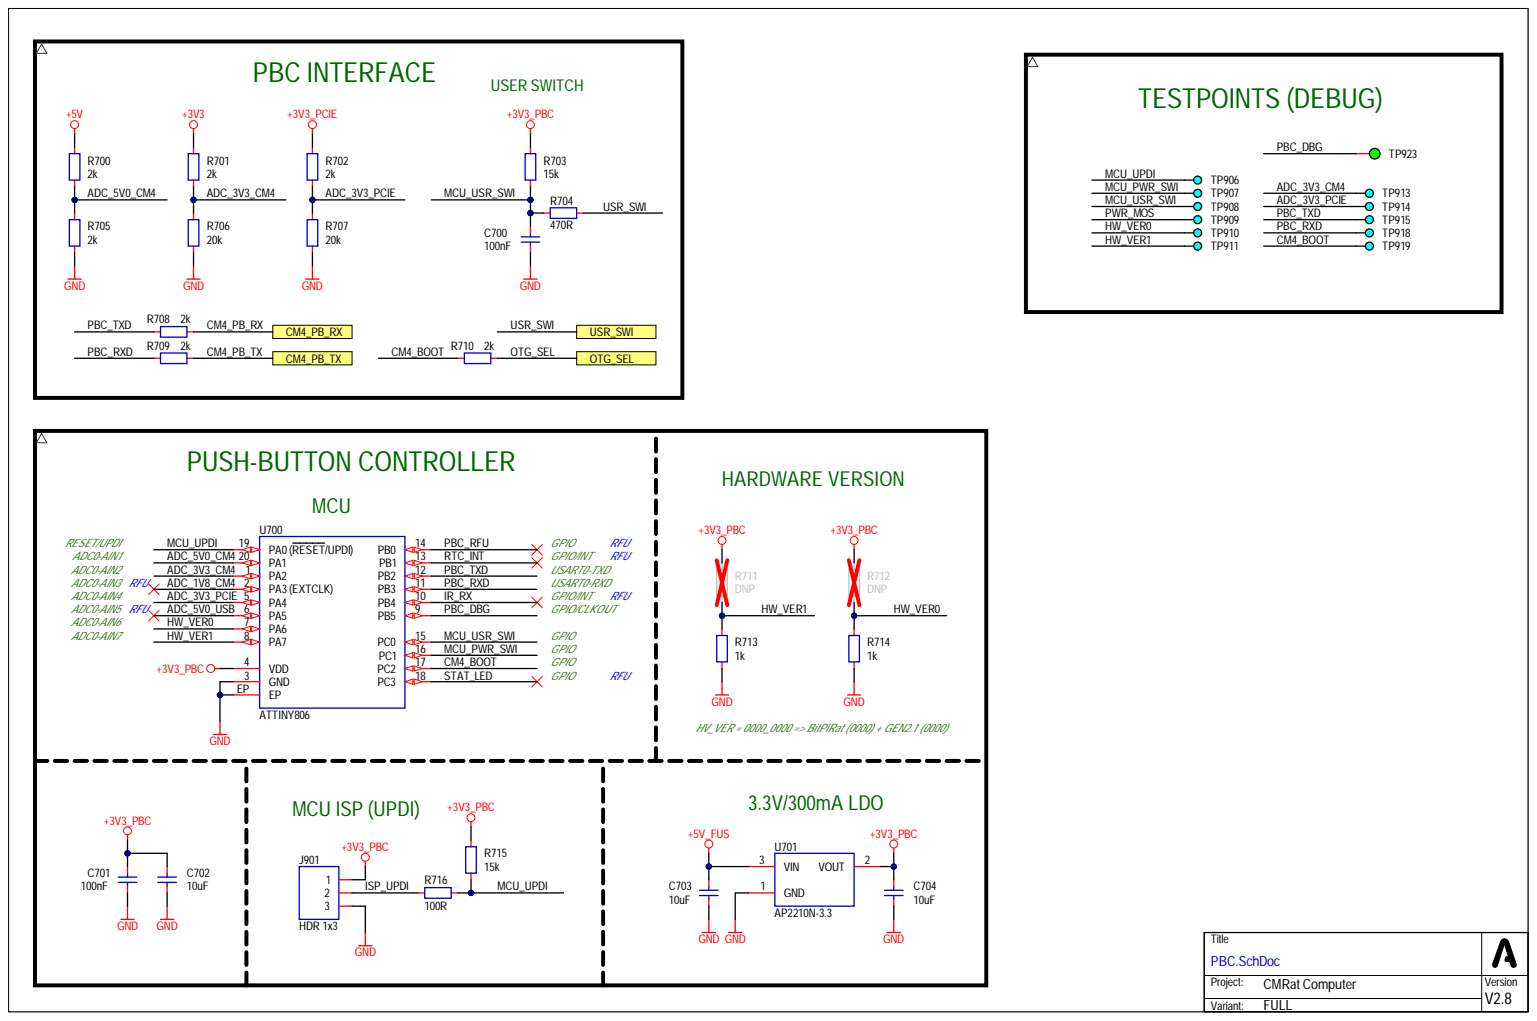
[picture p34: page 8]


STAND-OFF HEIGHT TABLE


BOM:
2.2uH -> compatible components (7.3x6.6x2.4mm):
Changjiang Microelectronics Tech, MPN = FXL0624-2R2-M
Sumida, MPN = 0624CDMCCDS-2R2MC
AVX, MPN = LMLP07B7M2R2DTAS


Radxa Lite (no eMMC)

SCH:
Used MicroSD card slot: Hmax = 2.00 mm

BOM:
MicroSD slot -> compatible components:
GCT, MPN = MEM2055-00-190-01-A
SOFNG, MPN = TF-015
HOAUC, MPN = HYC77-TF09-200
XUNPU, MPN = TF-115

USER:
SD Card only for CM4 Lite module with no
on-board Flash memory chip (eMMC).

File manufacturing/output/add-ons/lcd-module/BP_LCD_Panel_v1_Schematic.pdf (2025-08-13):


reference board: PINE64
les.pine64.org/doc/rockpro64/rockpro64_v21-SCH.pdf

GND Description: NGFF connector (NGFF), M-Key:

tors as close as

Mirko Electronics Smoka Wawel ski ego 1 30-535 Kra kó w, Pol a nd | Size B

Ti tl e LCD Front P anel for BitPiRat board | | Version V E R 1

Project: LCD Panel | | Revision RE V 1
Variant: [No Variations] | RefDes: 1-99
Designer: Smok Wawelski | Sheet:
Fi le Name: [01] BP_LCD_Panel_v1.SchDoc | Printed:

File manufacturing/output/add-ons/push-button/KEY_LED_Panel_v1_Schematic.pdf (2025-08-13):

# PCB MARKING

LAYER INDICATOR; PCB1; PCB_LAYER_STACKUP; FID1; Fiducial; FID2; FID3; FID4; FID5; FID6; 8pin (2x4pin); LED_ACT_OUT; LED_PWR_OUT; USR_SWI CM_I2C1_SDA CM_I2C1_SCL; GND; LED1 Green; LED2 Red; ACT LED; PWR LED; VLP-400-F; TACT Switch; USR_SWI

Mirko Electronics Smoka Wawelskiego 1 30-535 Kraków, Poland | Size B

Title LCD Front Panel for BitPiRat board | | Version VER1

Project: LCD Panel | | Revision REV1
Variant: [No Variations] | RefDes: 1-99
Designer: Smok Wawelski | Sheet: 1 1 /
File Name: | Printed: [01] KEY_LED_Panel_v1.SchDoc 17.05.2022
